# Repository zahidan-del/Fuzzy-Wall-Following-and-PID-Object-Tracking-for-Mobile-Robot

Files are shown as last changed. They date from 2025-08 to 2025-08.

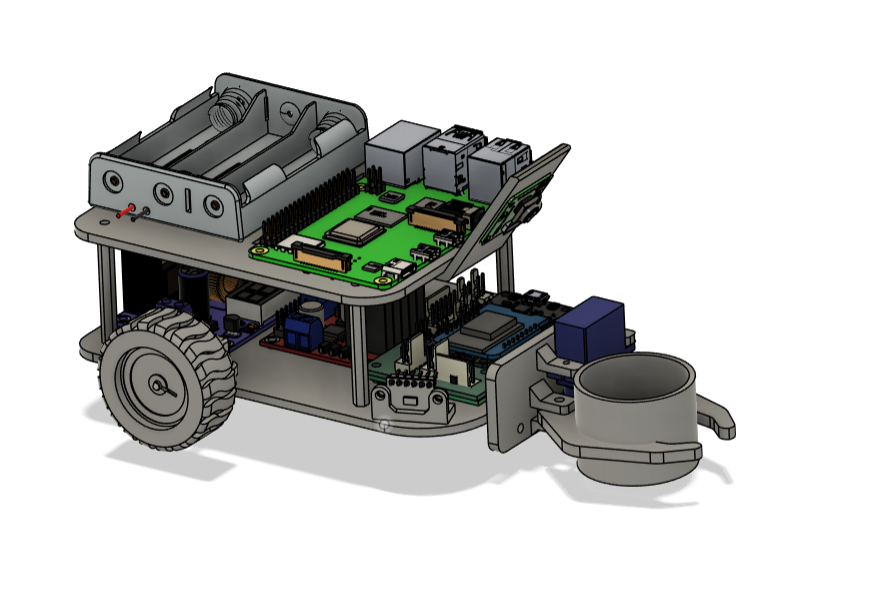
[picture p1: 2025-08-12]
3D Design/3D Design.png

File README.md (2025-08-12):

# Fuzzy Wall-Following and PID Object Tracking on Mobile Robot

This repository contains a **mobile robot** project with a hybrid control system combining a **Fuzzy Logic Controller** for wall-following navigation and a **PID Controller** for camera-based object tracking. The system uses a distributed architecture where the **Raspberry Pi 4 Model B** handles image processing and PID computation, while the **ESP32 Devkit V1** controls the actuators in real-time based on fuzzy logic and commands from the Raspberry Pi.  

---

## Key Features
- Wall-following navigation using **Fuzzy Logic Controller** based on VL53L0X distance sensor.  
- Camera-based object tracking using **PID Controller**.  
- **Raspberry Pi** integration for computer vision and **ESP32** for motor control.  
- Multi-tasking system capable of performing navigation and object tracking simultaneously.  
- Object detection based on HSV (*Hue, Saturation, Value*) for high accuracy under various lighting conditions.  

---

## Technologies Used
- **Raspberry Pi 4 Model B** – Computer vision processing and PID computation.  
- **ESP32 Devkit V1** – Real-time actuator control and fuzzy logic execution.  
- **Fuzzy Logic Controller (FLC)** – Handles uncertainty and non-linearity in robot navigation.  
- **PID Controller** – Adjusts robot’s speed and direction during object tracking.  
- **OpenCV (Python)** – HSV-based object detection from Raspberry Pi camera.  
- **Serial Communication (UART)** – Connects Raspberry Pi with ESP32.  

---

## Main Components Used
- **Raspberry Pi 4 Model B**  
- **ESP32 Devkit V1**  
- **SG90 Servo Motor** (for gripper control)  
- **Pi Camera** (Raspberry Pi camera for computer vision)  
- **N30 Micro Gear DC Motor** (wheel drive)  
- **L298N Motor Driver**  
- **XL4016 Step Down Converter** (voltage regulation)  
- **18650 Battery (x3)**  
- **3S 18650 Battery Holder**  

---

## Contact
📧 Email: [zahidan54@gmail.com](mailto:zhdn54@gmail.com)  
📷 Instagram: [@zhdnakhmad](https://instagram.com/zhdnakhmad)

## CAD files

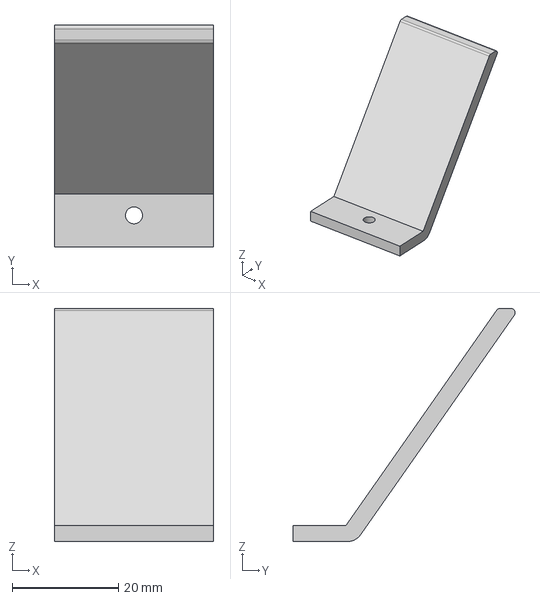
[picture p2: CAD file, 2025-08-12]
3D Design/Bracket Camera.step
30.0 x 41.9 x 44.0 mm

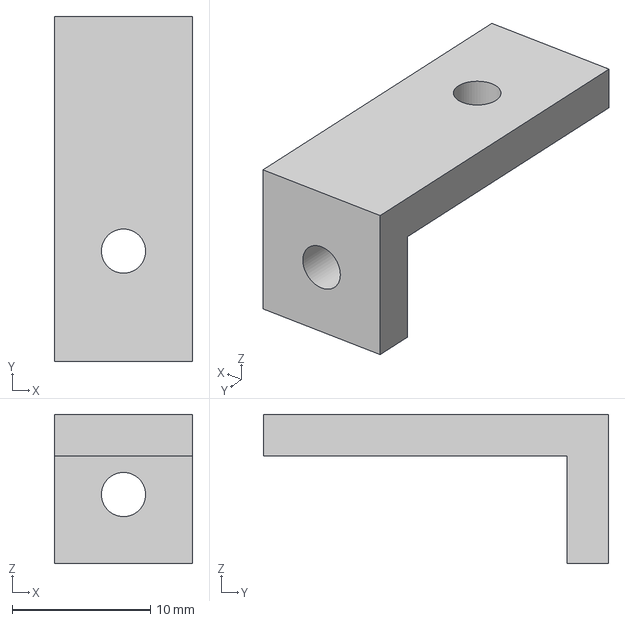
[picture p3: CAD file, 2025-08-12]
3D Design/Bracket Gripper.step
10.0 x 25.0 x 10.8 mm

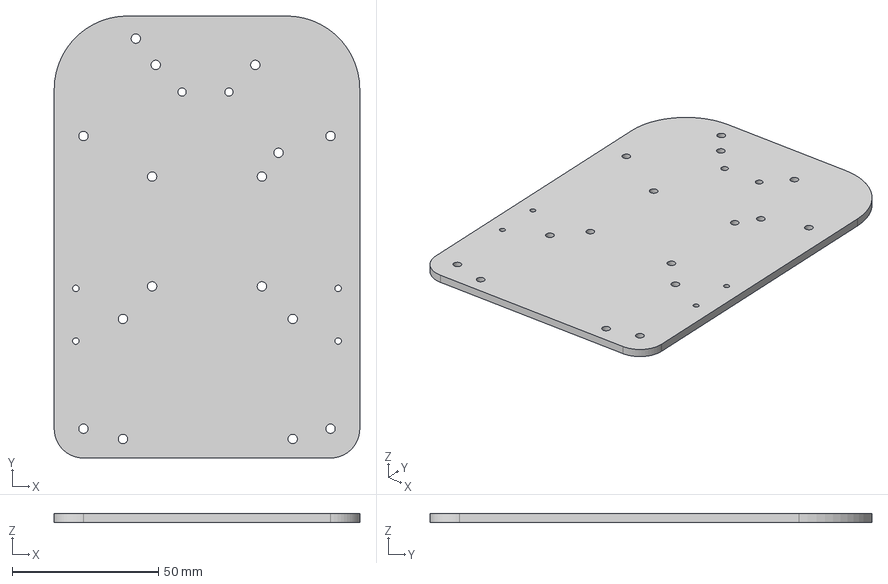
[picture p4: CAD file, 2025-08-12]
3D Design/lower body.step
104.4 x 151.0 x 3.00 mm

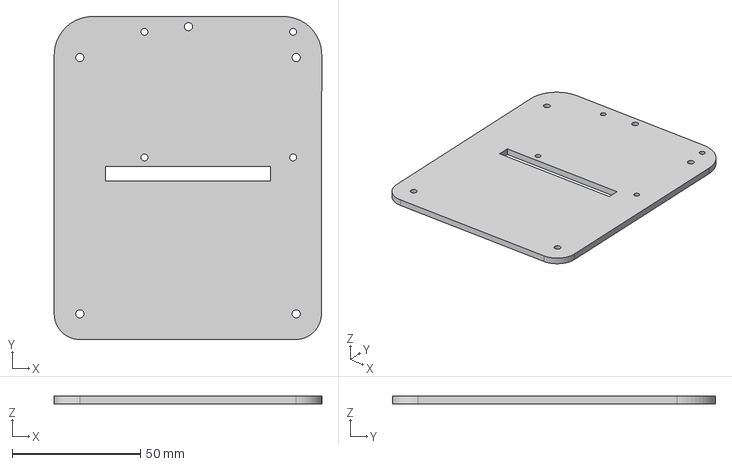
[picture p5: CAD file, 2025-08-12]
3D Design/Upper Body.step
104.4 x 126.0 x 3.00 mm

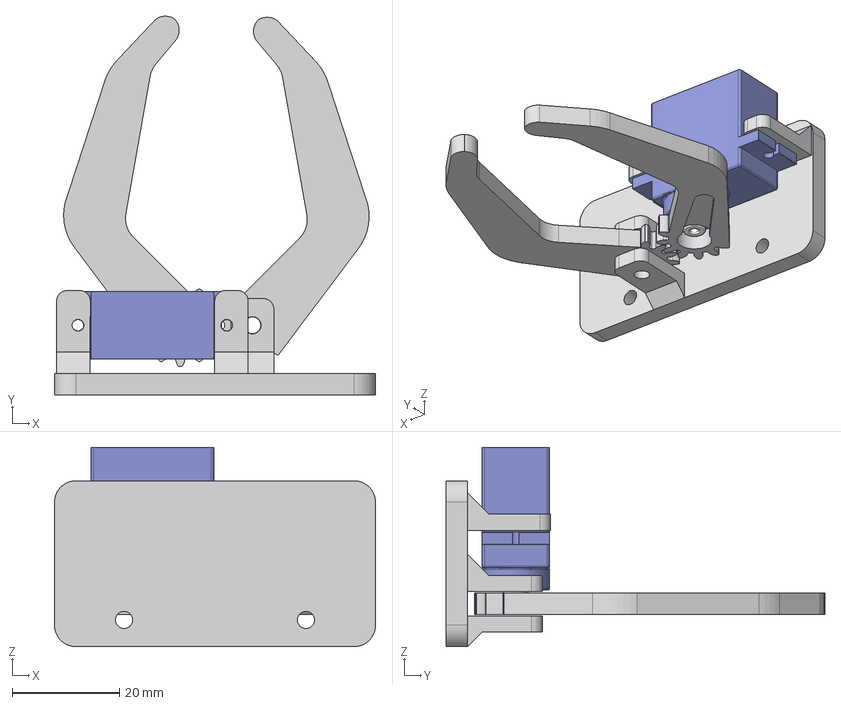
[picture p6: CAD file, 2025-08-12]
3D Design/Gripper.step
60.0 x 70.8 x 37.3 mm
Spur Gear (12 teeth)
Spur Gear (12 teeth) (1)
SG90

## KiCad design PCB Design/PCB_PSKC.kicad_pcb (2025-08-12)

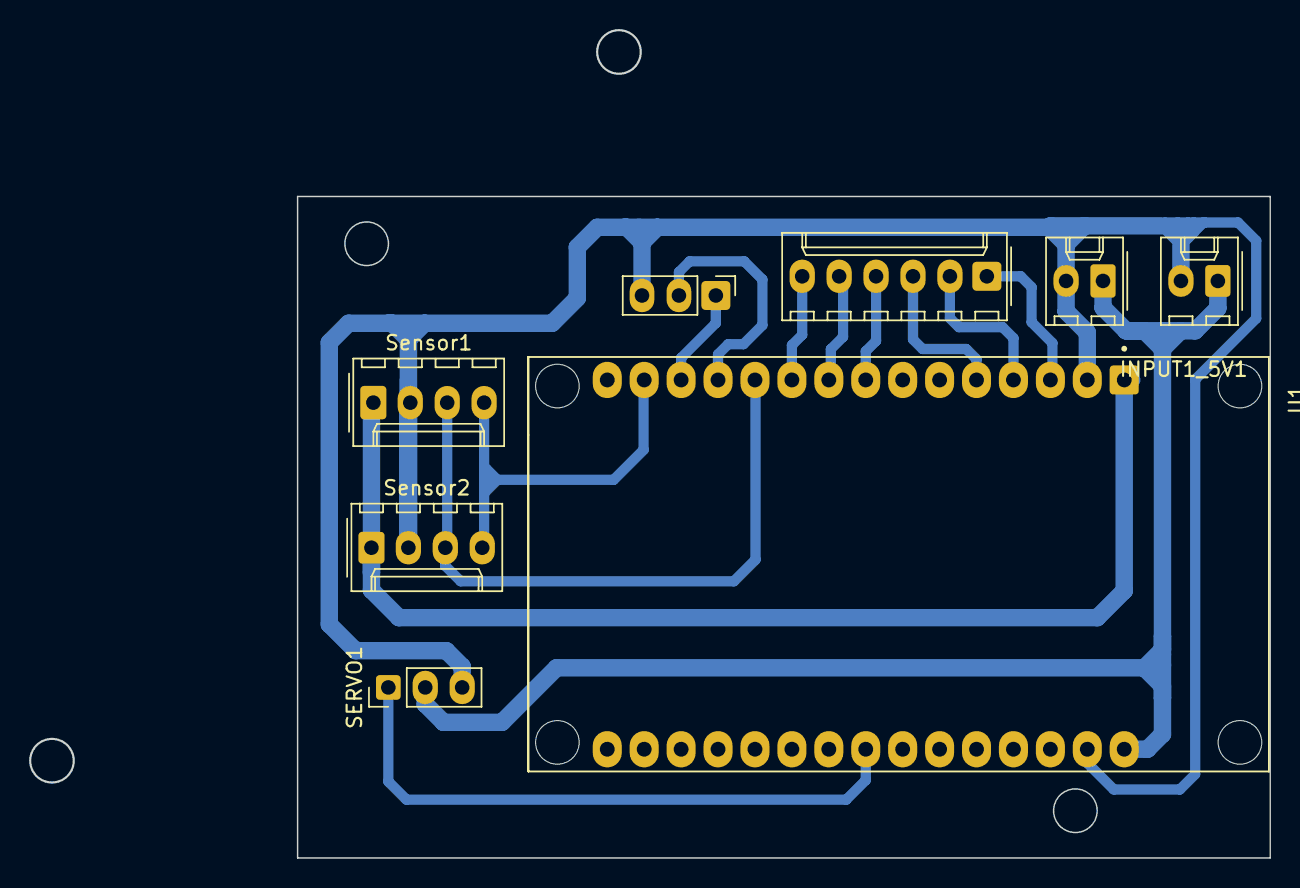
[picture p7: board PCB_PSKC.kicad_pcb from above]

Board: 2 copper layers, 66.9 x 45.5 mm, 8 parts (0 on the bottom side), 14 nets.

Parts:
COMMUNICATION1: Conn_01x03_Male; PinHeader_1x03_P2.54mm_Vertical
INPUT1_5V1: Conn_01x02_Male; Molex_KK-254_AE-6410-02A_1x02_P2.54mm_Vertical
INPUT_RASP1_5V1: Conn_01x02_Male; Molex_KK-254_AE-6410-02A_1x02_P2.54mm_Vertical
L298N1: Conn_01x06_Male; Molex_KK-254_AE-6410-06A_1x06_P2.54mm_Vertical
SERVO1: Conn_01x03_Male; PinHeader_1x03_P2.54mm_Vertical
Sensor1, Sensor2: Conn_01x04_Pin; Molex_KK-254_AE-6410-04A_1x04_P2.54mm_Vertical
U1: ESP32-DEVKIT-V1; MODULE_ESP32_DEVKIT_V1

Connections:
EN1: L298N1.1, U1.3 (D15)
EN2: L298N1.6, U1.10 (D19)
IN1: L298N1.2, U1.4 (D2)
IN2: L298N1.3, U1.5 (D4)
IN3: L298N1.4, U1.8 (D5)
IN4: L298N1.5, U1.9 (D18)
unnamed: COMMUNICATION1.3, INPUT1_5V1.2, INPUT_RASP1_5V1.2, SERVO1.3, Sensor1.2, Sensor2.2, U1.2 (GND), U1.29 (GND)
unnamed: INPUT1_5V1.1, INPUT_RASP1_5V1.1, SERVO1.2, U1.30 (VIN)
unnamed: Sensor1.1, Sensor2.1, U1.1 (3V3)
RX0: COMMUNICATION1.2, U1.12 (RX0)
SCL: Sensor1.3, Sensor2.3, U1.11 (D21)
SDA: Sensor1.4, Sensor2.4, U1.14 (D22)
Servo1: SERVO1.1, U1.23 (D25)
TX0: COMMUNICATION1.1, U1.13 (TX0)

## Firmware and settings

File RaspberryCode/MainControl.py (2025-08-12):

import threading
import time
from PIDControl import ObjectDetector
from FuzzyControl import WallFollower
import serial
import os
from datetime import datetime
import numpy as np

class MainController:
    def __init__(self):
        self.serial_port = '/dev/ttyS0'
        self.baud_rate = 115200
        self.resolution = (640, 480)
        self.close_zone = {
            'x_min': 160, 'x_max': 480,
            'y_min': 380, 'y_max': 410
        }
        self.color_lower = np.array([0, 230, 70])
        self.color_upper = np.array([70, 255, 255])

        self.log_filename = f"log_{datetime.now().strftime('%Y%m%d_%H%M%S')}.txt"
        self.log_path = os.path.join(os.getcwd(), self.log_filename)

        self.ser = serial.Serial(self.serial_port, self.baud_rate, timeout=0.1)
        self.detector = ObjectDetector(self.resolution, log_path=self.log_path)
        self.wall_follower = WallFollower(log_path=self.log_path)

        self.mode = "WALL"
        self.last_state = None
        self.running = True

        self.fuzzy_errors = []
        self.fuzzy_outputs = []
        self.pid_errors = []
        self.pid_outputs = []
        self.fuzzy_times = []
        self.pid_times = []
        self.start_time = time.time()


        threading.Thread(target=self.serial_thread, daemon=True).start()
        threading.Thread(target=self.object_tracking_thread, daemon=True).start()
        

    def serial_thread(self):
        print("[THREAD] Serial started")
        while self.running:
            self.handle_serial()
            time.sleep(1 / 80.0)

    def object_tracking_thread(self):
        print("[THREAD] Object tracking started")
        current_fps = 10  
        last_detection_time = time.time()
        
        while self.running:
            start_time = time.time()
            
            # Eksekusi object tracking
            self.object_tracking()
            
            # Periksa apakah ada deteksi objek
            if self.detector.last_detection_time > last_detection_time:
                current_fps = 30  
                last_detection_time = self.detector.last_detection_time
            elif time.time() - last_detection_time > 2.0:  
                current_fps = 10 
            
            # Hitung waktu eksekusi dan sleep
            execution_time = time.time() - start_time
            sleep_time = max(0, (1.0 / current_fps) - execution_time)
            time.sleep(sleep_time)

    def handle_serial(self):
        if self.ser.in_waiting:
            line = self.ser.readline().decode(errors='ignore').strip()
            print(f"[SERIAL RAW] {line}")
            if line.startswith("DIST:") and self.mode == "WALL":
                try:
                    distance = int(line.split(':')[1])
                    if 0 < distance < 2000:
                        output, fuzzy_error = self.wall_follower.fuzzy_control(distance, return_error=True)
                        self.fuzzy_errors.append(fuzzy_error)
                        self.fuzzy_outputs.append(output)
                        elapsed_time = time.time() - self.start_time
                        self.fuzzy_times.append(elapsed_time)
                        self.control_motors(output)
                        print(f"[WALL] Distance: {distance}, Output: {output:.2f}")
                except ValueError:
                    print(f"[ERROR] Invalid data: {line}")

    def control_motors(self, correction=0, left_speed=None, right_speed=None):
        if not self.ser or not self.ser.is_open:
            print("[WARNING] Serial port not open. Skipping motor command.")
            return

        base_speed = 50
        max_speed = 130
        if left_speed is None or right_speed is None:
            left_speed = base_speed + correction
            right_speed = base_speed - correction
        left_speed = int(np.clip(left_speed, -max_speed, max_speed))
        right_speed = int(np.clip(right_speed, -max_speed, max_speed))
        command = f"MOTOR:{left_speed},{right_speed}\n"
        self.ser.write(command.encode())
        print(f"[MOTOR] {command.strip()}")

    def object_tracking(self):
        detection = self.detector.detect(self.color_lower, self.color_upper, self.close_zone)
        current_state = detection['state']

        # Jika state berubah, kirim ke gripper
        if current_state != self.last_state:
            self.ser.write(f"{current_state}\n".encode())
            print(f"[GRIPPER] State: {current_state}")
            self.last_state = current_state

        if current_state == "OPEN" and detection['cx'] is not None:
            self.mode = "OBJECT"
            corr, pid_error = self.detector.compute_pid(detection['cx'], return_error=True)
            self.pid_errors.append(pid_error)
            self.pid_outputs.append(corr)
            elapsed_time = time.time() - self.start_time
            self.pid_times.append(elapsed_time)
            left = self.detector.pid_params['base_speed'] - corr
            right = self.detector.pid_params['base_speed'] + corr
            self.control_motors(left_speed=left, right_speed=right)


        elif current_state == "CLOSE":
            self.mode = "OBJECT"
            self.control_motors(left_speed=0, right_speed=0)

        elif current_state == "INITIAL":
            self.mode = "WALL"

    def save_logs(self):
        with open(self.log_path, "w") as f:
            f.write("Fuzzy Error:\n")
            f.write(", ".join(f"{val:.2f}" for val in self.fuzzy_errors) + "\n\n")
            f.write("Fuzzy Output:\n")
            f.write(", ".join(f"{val:.2f}" for val in self.fuzzy_outputs) + "\n\n")
            f.write("Fuzzy Time:\n")
            f.write(", ".join(f"{val:.2f}" for val in self.fuzzy_times) + "\n\n")
            f.write("PID Error:\n")
            f.write(", ".join(f"{val:.2f}" for val in self.pid_errors) + "\n\n")
            f.write("PID Output:\n")
            f.write(", ".join(f"{val:.2f}" for val in self.pid_outputs) + "\n\n")
            f.write("PID Time:\n")
            f.write(", ".join(f"{val:.2f}" for val in self.pid_times) + "\n\n")


    def run(self):
        print("[SYSTEM] Controller started")
        try:
            while True:
                time.sleep(1)
        except KeyboardInterrupt:
            self.running = False
            print("[SYSTEM] Shutting down...")
        finally:
            self.cleanup()

    def cleanup(self):
        self.save_logs()
        self.detector.cleanup()
        self.ser.close()

if __name__ == "__main__":
    controller = MainController()
    controller.run()

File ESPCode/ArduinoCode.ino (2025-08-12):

#include <Wire.h>
#include <VL53L0X.h>
#include <ESP32Servo.h>  /

VL53L0X sensor;

// Pin motor
#define ENA 15
#define IN1 18
#define IN2 5
#define IN3 4
#define IN4 2
#define ENB 19

// Servo
#define SERVO_PIN 25  
Servo gripperServo;
const int SERVO_OPEN_POS = 60;
const int SERVO_CLOSE_POS = 98;
const int SERVO_INITIAL_POS = 110;

unsigned long lastCommandTime = 0;             
const unsigned long commandTimeout = 500;      

void setup() {
  Serial.begin(115200);
  Wire.begin();

  // Inisialisasi sensor
  if (!sensor.init()) {
    Serial.println("Sensor gagal!");
    while (1);
  }
  sensor.startContinuous();

  // Inisialisasi motor
  pinMode(ENA, OUTPUT);
  pinMode(ENB, OUTPUT);
  pinMode(IN1, OUTPUT);
  pinMode(IN2, OUTPUT);
  pinMode(IN3, OUTPUT);
  pinMode(IN4, OUTPUT);
  stopMotors();

  // Inisialisasi servo
  gripperServo.attach(SERVO_PIN);
  delay(300);
  gripperServo.write(SERVO_INITIAL_POS);  
}

void loop() {
  // 1. Baca sensor dan kirim ke Raspberry Pi
  int distance = sensor.readRangeContinuousMillimeters();
  Serial.println("DIST:" + String(distance));  

  // 2. Baca perintah dari Raspberry Pi
  if (Serial.available()) {
    String command = Serial.readStringUntil('\n');
    command.trim();

    if (command.startsWith("MOTOR:")) {
      executeMotorCommand(command);
      lastCommandTime = millis();
    } else if (command == "STOP") {
      stopMotors();
      lastCommandTime = 0;
    } else if (command == "OPEN") {
      gripperServo.write(SERVO_OPEN_POS);
    } else if (command == "CLOSE") {
      gripperServo.write(SERVO_CLOSE_POS);
    }
  }

  // 3. Cek timeout
  if (millis() - lastCommandTime > commandTimeout) {
    stopMotors();
  }

  delay(50);
}

void executeMotorCommand(String cmd) {
  int commaIndex = cmd.indexOf(',');
  int left_speed = cmd.substring(6, commaIndex).toInt();
  int right_speed = cmd.substring(commaIndex + 1).toInt();

  digitalWrite(IN1, (right_speed >= 0) ? HIGH : LOW);
  digitalWrite(IN2, (right_speed >= 0) ? LOW : HIGH);
  analogWrite(ENA, constrain(abs(right_speed), 0, 255));

  digitalWrite(IN3, (left_speed >= 0) ? HIGH : LOW);
  digitalWrite(IN4, (left_speed >= 0) ? LOW : HIGH);
  analogWrite(ENB, constrain(abs(left_speed), 0, 255));
}

void stopMotors() {
  digitalWrite(IN1, LOW);
  digitalWrite(IN2, LOW);
  digitalWrite(IN3, LOW);
  digitalWrite(IN4, LOW);
  analogWrite(ENA, 0);
  analogWrite(ENB, 0);
}

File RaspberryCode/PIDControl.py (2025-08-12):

import cv2
import numpy as np
from picamera2 import Picamera2
import time

class ObjectDetector:
    def _init_(self, resolution=(640, 480), log_path="pid_log.txt"):
        self.cam = Picamera2()
        config = self.cam.create_preview_configuration(
            main={"format": "RGB888", "size": resolution}
        )
        self.cam.configure(config)
        self.cam.start()
        self.resolution = resolution
        
        self.log_path = log_path
        self.last_detection_time = 0

        # PID Parameters
        self.pid_params = {
            'Kp': 0.1, 'Ki': 0.04, 'Kd': 0.008,
            'dt': 1/30.0, 'base_speed': 45,
            'max_speed': 100, 'center_x': resolution[0] // 2,
            'integral': 0.0, 'last_error': 0.0
        }

    def compute_pid(self, cx, return_error=False):
        error = cx - self.pid_params['center_x']
        self.pid_params['integral'] += error * self.pid_params['dt']
        derivative = (error - self.pid_params['last_error']) / self.pid_params['dt']
        
        corr = (self.pid_params['Kp'] * error +
                self.pid_params['Ki'] * self.pid_params['integral'] +
                self.pid_params['Kd'] * derivative)
        
        corr = np.clip(corr, -self.pid_params['base_speed'], self.pid_params['base_speed'])
        self.pid_params['last_error'] = error

        if return_error:
            return corr, error
        return corr


    def detect(self, color_lower, color_upper, close_zone):
        """Deteksi objek dan return state serta posisi"""
        frame = self.cam.capture_array()
        frame = cv2.rotate(frame, cv2.ROTATE_180)
        
        # Threshold warna
        hsv = cv2.cvtColor(frame, cv2.COLOR_RGB2HSV)
        mask = cv2.inRange(hsv, color_lower, color_upper)
        
        # Noise reduction
        kernel = cv2.getStructuringElement(cv2.MORPH_ELLIPSE, (5, 5))
        mask = cv2.morphologyEx(mask, cv2.MORPH_OPEN, kernel, iterations=1)
        mask = cv2.morphologyEx(mask, cv2.MORPH_CLOSE, kernel, iterations=2)
        
        # Cari kontur
        contours, _ = cv2.findContours(mask, cv2.RETR_EXTERNAL, cv2.CHAIN_APPROX_SIMPLE)
        
        # Default values
        result = {
            'state': "INITIAL",
            'cx': None,
            'cy': None,
            'frame': frame,
            'mask': mask
        }
        
        # Proses kontur
        for cnt in contours:
            if cv2.contourArea(cnt) < 500 or cv2.boundingRect(cnt)[3] < 100:
                continue
                
            x, y, w, h = cv2.boundingRect(cnt)
            cx, cy = x + w//2, y + h//2
            
            result.update({
                'state': "OPEN",
                'cx': cx,
                'cy': cy
            })

            #Update waktu deteksi terakhir
            self.last_detection_time = time.time()
            
            # Gambar annotations
            cv2.rectangle(frame, (x, y), (x+w, y+h), (0, 0, 255), 2)
            cv2.circle(frame, (cx, cy), 5, (0, 0, 255), -1)
            cv2.putText(frame, f"({cx},{cy})", (x, y-10), 
                       cv2.FONT_HERSHEY_SIMPLEX, 0.5, (0, 255, 0), 1)
            
            # Cek zona CLOSE
            if (close_zone['x_min'] <= cx <= close_zone['x_max'] and
                close_zone['y_min'] <= cy <= close_zone['y_max']):
                result['state'] = "CLOSE"
            
            break
        
        return result

    def cleanup(self):
        self.cam.stop()

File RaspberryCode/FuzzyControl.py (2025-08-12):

import numpy as np

class WallFollower:

    def _init_(self, target_distance=100, log_path="wall_log.txt"):
        self.last_distance = target_distance
        self.target_distance = target_distance
        self.log_path = log_path
    
    def fuzzy_control(self, distance, return_error=False):
        """Fuzzy logic controller untuk navigasi dinding"""
        error = distance - self.target_distance
        delta_error = error - (self.last_distance - self.target_distance)
        self.last_distance = distance

        # Fungsi keanggotaan error
        e_nb = max(0, min(1, (-error - 40) / 40.0)) if error < -40 else 0
        e_ns = max(0, min(1, (-error) / 40.0, (error + 80) / 40.0)) if -80 < error < 0 else 0
        e_ze = max(0, min(1, (error + 40) / 40.0, (-error + 40) / 40.0)) if -40 < error < 40 else 0
        e_ps = max(0, min(1, (error) / 40.0, (-error + 80) / 40.0)) if 0 < error < 80 else 0
        e_pb = max(0, min(1, (error - 40) / 40.0)) if error > 40 else 0

        # Fungsi keanggotaan delta error
        de_neg = max(0, -delta_error / 20.0) if delta_error < 0 else 0
        de_zero = max(0, 1 - abs(delta_error) / 20.0)
        de_pos = max(0, delta_error / 20.0) if delta_error > 0 else 0

        # Rule base
        rule_weights = [
            min(e_nb, de_neg), min(e_nb, de_zero), min(e_nb, de_pos),
            min(e_ns, de_neg), min(e_ns, de_zero), min(e_ns, de_pos),
            min(e_ze, de_neg), min(e_ze, de_zero), min(e_ze, de_pos),
            min(e_ps, de_neg), min(e_ps, de_zero), min(e_ps, de_pos),
            min(e_pb, de_neg), min(e_pb, de_zero), min(e_pb, de_pos)
        ]
        
        rule_outputs = [
            40, 30, 20, 25, 15, 5, 10, 0, -10, -5, -15, -25, -20, -30, -40
        ]

        # Hitung output
        numerator = sum(w * o for w, o in zip(rule_weights, rule_outputs))
        denominator = sum(rule_weights)
        
        output = numerator / denominator if denominator != 0 else 0

        # Logging
        with open(self.log_path, "a") as f:
            f.write(f"Fuzzy Error: {error:.2f}\n")
            f.write(f"Fuzzy OUT: {output:.2f}\n")

        if return_error:
            return output, error
        return output
